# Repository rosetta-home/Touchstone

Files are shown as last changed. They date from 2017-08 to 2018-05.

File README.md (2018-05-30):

# Open Source Indoor Air Quality Sensor
An open hardware and software indoor air quality sensor provided by the [National Association of REALTORS](http://realtor.org) and [CRT Labs](https://crtlabs.org) in collaboration with the [Built Environment Research Group](http://built-envi.com/) at Illinois Institute of Technology.

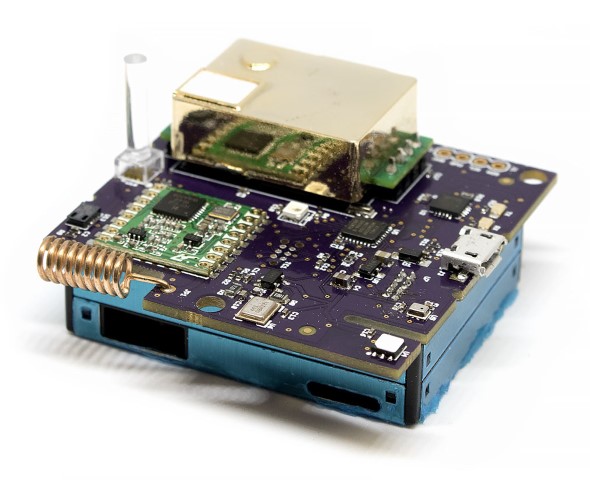
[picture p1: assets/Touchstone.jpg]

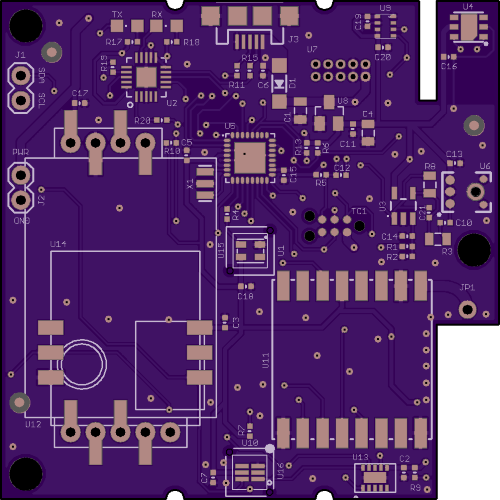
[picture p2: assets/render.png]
bruh


**Features**:
* Can measure upto 8 indoor environmental quality parameters (listed below)
* Atmel ATmega328P 16MHz 8-bit processor (based on Arduino platform)
* Genuine FTDI chip for serial communication with host computer
* Mini RGB LED for status and notification
* Programmable button for custom actions such as reset, configuration, etc.
* Long range wireless data transfer using FSK radio (no dependence on WiFi, cellular, etc.)
* Small footprint PCB board (less than 2x2 inches or 50x50mm)
* Low power requirements (35mA idle with all sensors running, 190mA peak during wireless data transfer)

**Measurement Points**:
* Temperature (Si7021)
* Relative Humidity (Si7021)
* VOC (Volatile Organic Compounds) (CCS811/IAQ-Core)
* CO2 (MH-z19)
* Particulate Matter, PM2.5 (PMS7003)
* Barometric Pressure (BMP280)
* Light Intensity (TSL2591)
* Sound Intensity (Electret Microphone)

**Connectivity**:
* FSK radio (RFM69HW 915MHz)
* MicroUSB (FTDI FX231XQ)

License:
Apache License Version 2.0

For the Raspberry Pi HAT, please visit the [PiAQ Website](http://piaq.io) and [repository](https://github.com/NationalAssociationOfRealtors/PiAQ)

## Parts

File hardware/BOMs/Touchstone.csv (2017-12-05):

Qty | Value | Device | Package | Parts | Description | AVAILABILITY | DESCRIPTION | MF | MP | MPN | OC_NEWARK | PACKAGE | PRICE | PROD_ID | SF_ID | SF_SKU | VALUE
2 |  | LEDCHIPLED_0805 | CHIPLED_0805 | RX, TX | LED |  |  |  |  | LG R971-KN-1 | unknown
2 |  | M02PTH | 1X02 | J1, J2 | Standard 2-pin 0.1 header. Use with"
12 | 0.1uF | MICROBUILDER_CAP_CERAMIC_0402MP | MICROBUILDER__0402MP | C3, C5, C6, C7, C8, C11, C12, C15, C16, C17, C19, C20 | Ceramic Capacitors |  |  |  |  | GRM155R71C104KA88J
2 | 0878980426 | 0878980426 | CONN_4POS_VERT_2.54_SMD | U$4, U$5 | CONN HEADER 4POS VERT 2.54MM SMD |  |  |  |  | 0878980426
2 | 100 | MICROBUILDER_RESISTOR_0402MP | MICROBUILDER__0402MP | R25, R32 | Resistors |  |  |  |  | RC0402FR-07100RL
2 | 100K | MICROBUILDER_RESISTOR_0402MP | MICROBUILDER__0402MP | R9, R12 | Resistors |  |  |  |  | RC0402FR-07100KL
11 | 10K | MICROBUILDER_RESISTOR_0402MP | MICROBUILDER__0402MP | R5, R6, R7, R10, R13, R16, R21, R26, R28, R29, R30 | Resistors |  |  |  |  | RC0402JR-0710KL
1 | 10uF | CAP0805 | 0805 | C4 | Capacitor |  |  |  |  | CC0805KKX5R6BB106
2 | 10uF | MICROBUILDER_CAP_CERAMIC_0402MP | MICROBUILDER__0402MP | C9, C22 | Ceramic Capacitors |  |  |  |  | GRJ155R60J106ME11D
2 | 120mA/40V/370mV | DIODE-SCHOTTKY-RB751S40 | SOD-523 | D3, D4 | Schottky diode |  |  |  |  | RB751S40T1G |  |  |  | DIO-11018 |  |  | 120mA/40V/370mV
1 | 16 MHz | RESONATORSMD | RESONATOR-SMD | X1 | Resonator |  |  |  |  | CSTCE16M0V53-R0
4 | 1K | MICROBUILDER_RESISTOR_0402MP | MICROBUILDER__0402MP | R19, R20, R22, R27 | Resistors |  |  |  |  | RC0402JR-071KL
1 | 1uF | CAP0805 | 0805 | C1 | Capacitor |  |  |  |  | CC0805ZRY5V8BB105
4 | 1uF | MICROBUILDER_CAP_CERAMIC_0402MP | MICROBUILDER__0402MP | C2, C18, C23, C24 | Ceramic Capacitors |  |  |  |  | CC0402KRX5R6BB105
1 | 2.2K | MICROBUILDER_RESISTOR_0402MP | MICROBUILDER__0402MP | R23 | Resistors |  |  |  |  | RC0402FR-072K2L
1 | 22K | MICROBUILDER_RESISTOR_0402MP | MICROBUILDER__0402MP | R31 | Resistors |  |  |  |  | RC0402JR-0722KL
2 | 27 | MICROBUILDER_RESISTOR_0402MP | MICROBUILDER__0402MP | R11, R15 | Resistors |  |  |  |  | RC0402JR-0727RL
3 | 470 | MICROBUILDER_RESISTOR_0402MP | MICROBUILDER__0402MP | R4, R17, R18 | Resistors |  |  |  |  | RC0402JR-07470RL
1 | 470K | MICROBUILDER_RESISTOR_0402MP | MICROBUILDER__0402MP | R24 | Resistors |  |  |  |  | RC0402FR-071ML
1 | 915MHz | RFM69HCW-915 | RFM69HCW-XXXS2 | U11 | Hope RF RFM69H ISM Transceiver Module |  |  |  |  | RFM69HCW |  |  |  | IC-11997 |  |  | 915MHz
1 | ATMEGA328P-MU | ATMEGA328P-MU | QFN50P500X500X100-33N | U5 | ATmega Series 20 MHz 32 KB Flash 2 KB SRAM 8-Bit Microcontroller - QFN-32 | Good | ATmega Series 20 MHz 32 KB Flash 2 KB SRAM 8-Bit Microcontroller - QFN-32 | Atmel | ATMEGA328P-MU | ATMEGA328P-MU |  | QFN-32 Atmel | 2.55 USD
1 | Antenna | PINHD-1X1CB | 1X01-CLEANBIG | JP1 | Pin header 1x1 for 0.1 spacing" |  |  |  |  | Helical antenna
1 | BMP280 | BMP280 | BMP280 | U9 | The BMP280 is an absolute barometric pressure sensor especially designed for mobile applications. The sensor module is housed in an extremely compact 8-pin metal-lid LGA package with a footprint of only 2.0 × 2.5 mm2 and 0.95 mm package height. Its small |  |  |  |  | BMP280
1 | CCS811-I2C | CCS811-I2C | LGA | U13 |  |  |  |  |  | CCS811
1 | CONN_HDR_1.27MM_SMD_4POS | CONN_HDR_1.27MM_SMD_4POS | CONN_HDR_1.27MM_SMD_4POS | U$6 | MPN: M50-3630442 |  |  |  |  | M50-3630442
4 | FIDUCIAL | FIDUCIAL | FIDUCIAL_1MM | U$1, U$2, U$3, U$7 | For use by pick and place machines to calibrate the vision/machine, 1mm
1 | FT231XQ-R | FT231XQ-R | FTDI_FT231XQ-R_PACKAGE | U2 | This is the 20-LD QFN package of the FTDI FT231XQ-R chip. |  |  |  |  | FT231XQ-R
1 | IAQ-CORE-C | IAQ-CORE-C | IAQ-CORE-C | U14 | AMS IAQ-Core |  |  |  |  | IAQ-CORE-C
1 | LMV324QT | LMV324QT | QFN-16_3X3 | U17 |  |  |  |  |  | LM324QT
1 | MCP1703CB | MCP1703CB | SOT23 | U8 | 250 mA, 16V, Low Quiescent Current LDO Regulator |  |  |  |  | MCP1703T-3302E/CB | 18T9177
1 | MH-Z19 | MH-Z19 | MH-Z19 | U12 | MH-z19 Footprint |  |  |  |  | MH-z19
1 | MIC2-PTH | MIC2-PTH | MICROPHONE-PTH-4.0MM | MK1 | Mini Electret Microphone |  |  |  |  | TOM-1545P-R |  |  |  | COMP-08856 | COM-08635
1 | MOMENTARY-SWITCH-SPST-SMD-6.0X3.5MM | MOMENTARY-SWITCH-SPST-SMD-6.0X3.5MM | TACTILE_SWITCH_SMD_6.0X3.5MM | S1 | Momentary Switch (Pushbutton) - SPST |  |  |  |  | RS-032G05A3-SM RT |  |  |  | SWCH-00815 |  | COM-08229
1 | NEOPIXEL_NANO_2427 | NEOPIXEL_NANO_2427 | SK6805-2427 | U1 |  |  |  |  |  | 3484
1 | PMS7003 | PMS7003 | PMS7003_RECEPTACLE_1.27MM_2X5 | U7 | 2x5 header 1.27mm pitch |  |  |  |  | 20021311-00012T4LF
1 | SI7021 | SI7021 | DFN-6-3X3-SI7021 | U4 | Silicon Labs Si7021 I2C Humidity and Temperature Sensor |  |  |  |  | SI7021-A20-GM1 |  |  |  | IC-13093
1 | SOD123 | MICROBUILDER_DIODE-SCHOTTKYSOD-123 | MICROBUILDER_SOD-123 | D1 |  |  |  |  |  | SD103AW-13-F
3 | STAND-OFF | STAND-OFF | STAND-OFF | H1, H2, H3 | #4 Stand Off
1 | TC2030-IDC-NL | TC2030-IDC-NL | TC2030-IDC-NL | TC1 | Tag-Connect In Circuit Programming & Debug Cable 6 Pin
1 | TSL2591 | LIGHT_TSL2591 | DFN6_TAOS | U10 | TSL2591 Light-To-Digital Sensor |  |  |  |  | TSL25911FN
1 | USB-MICROB | USB-MICROB | USB-MICROB | J3 | USB Connectors |  |  |  |  | ZX62-B-5PA(33) |  |  |  | CONN-09505
1 | VLP-450-F | VLP-450-F | VLP-450-F | U16 |  |  |  |  |  | VLP-550-F
1 | VLP-450-F | VLP-450-F | VLP-450-F | U15 |  |  |  |  |  | VLP-650-F

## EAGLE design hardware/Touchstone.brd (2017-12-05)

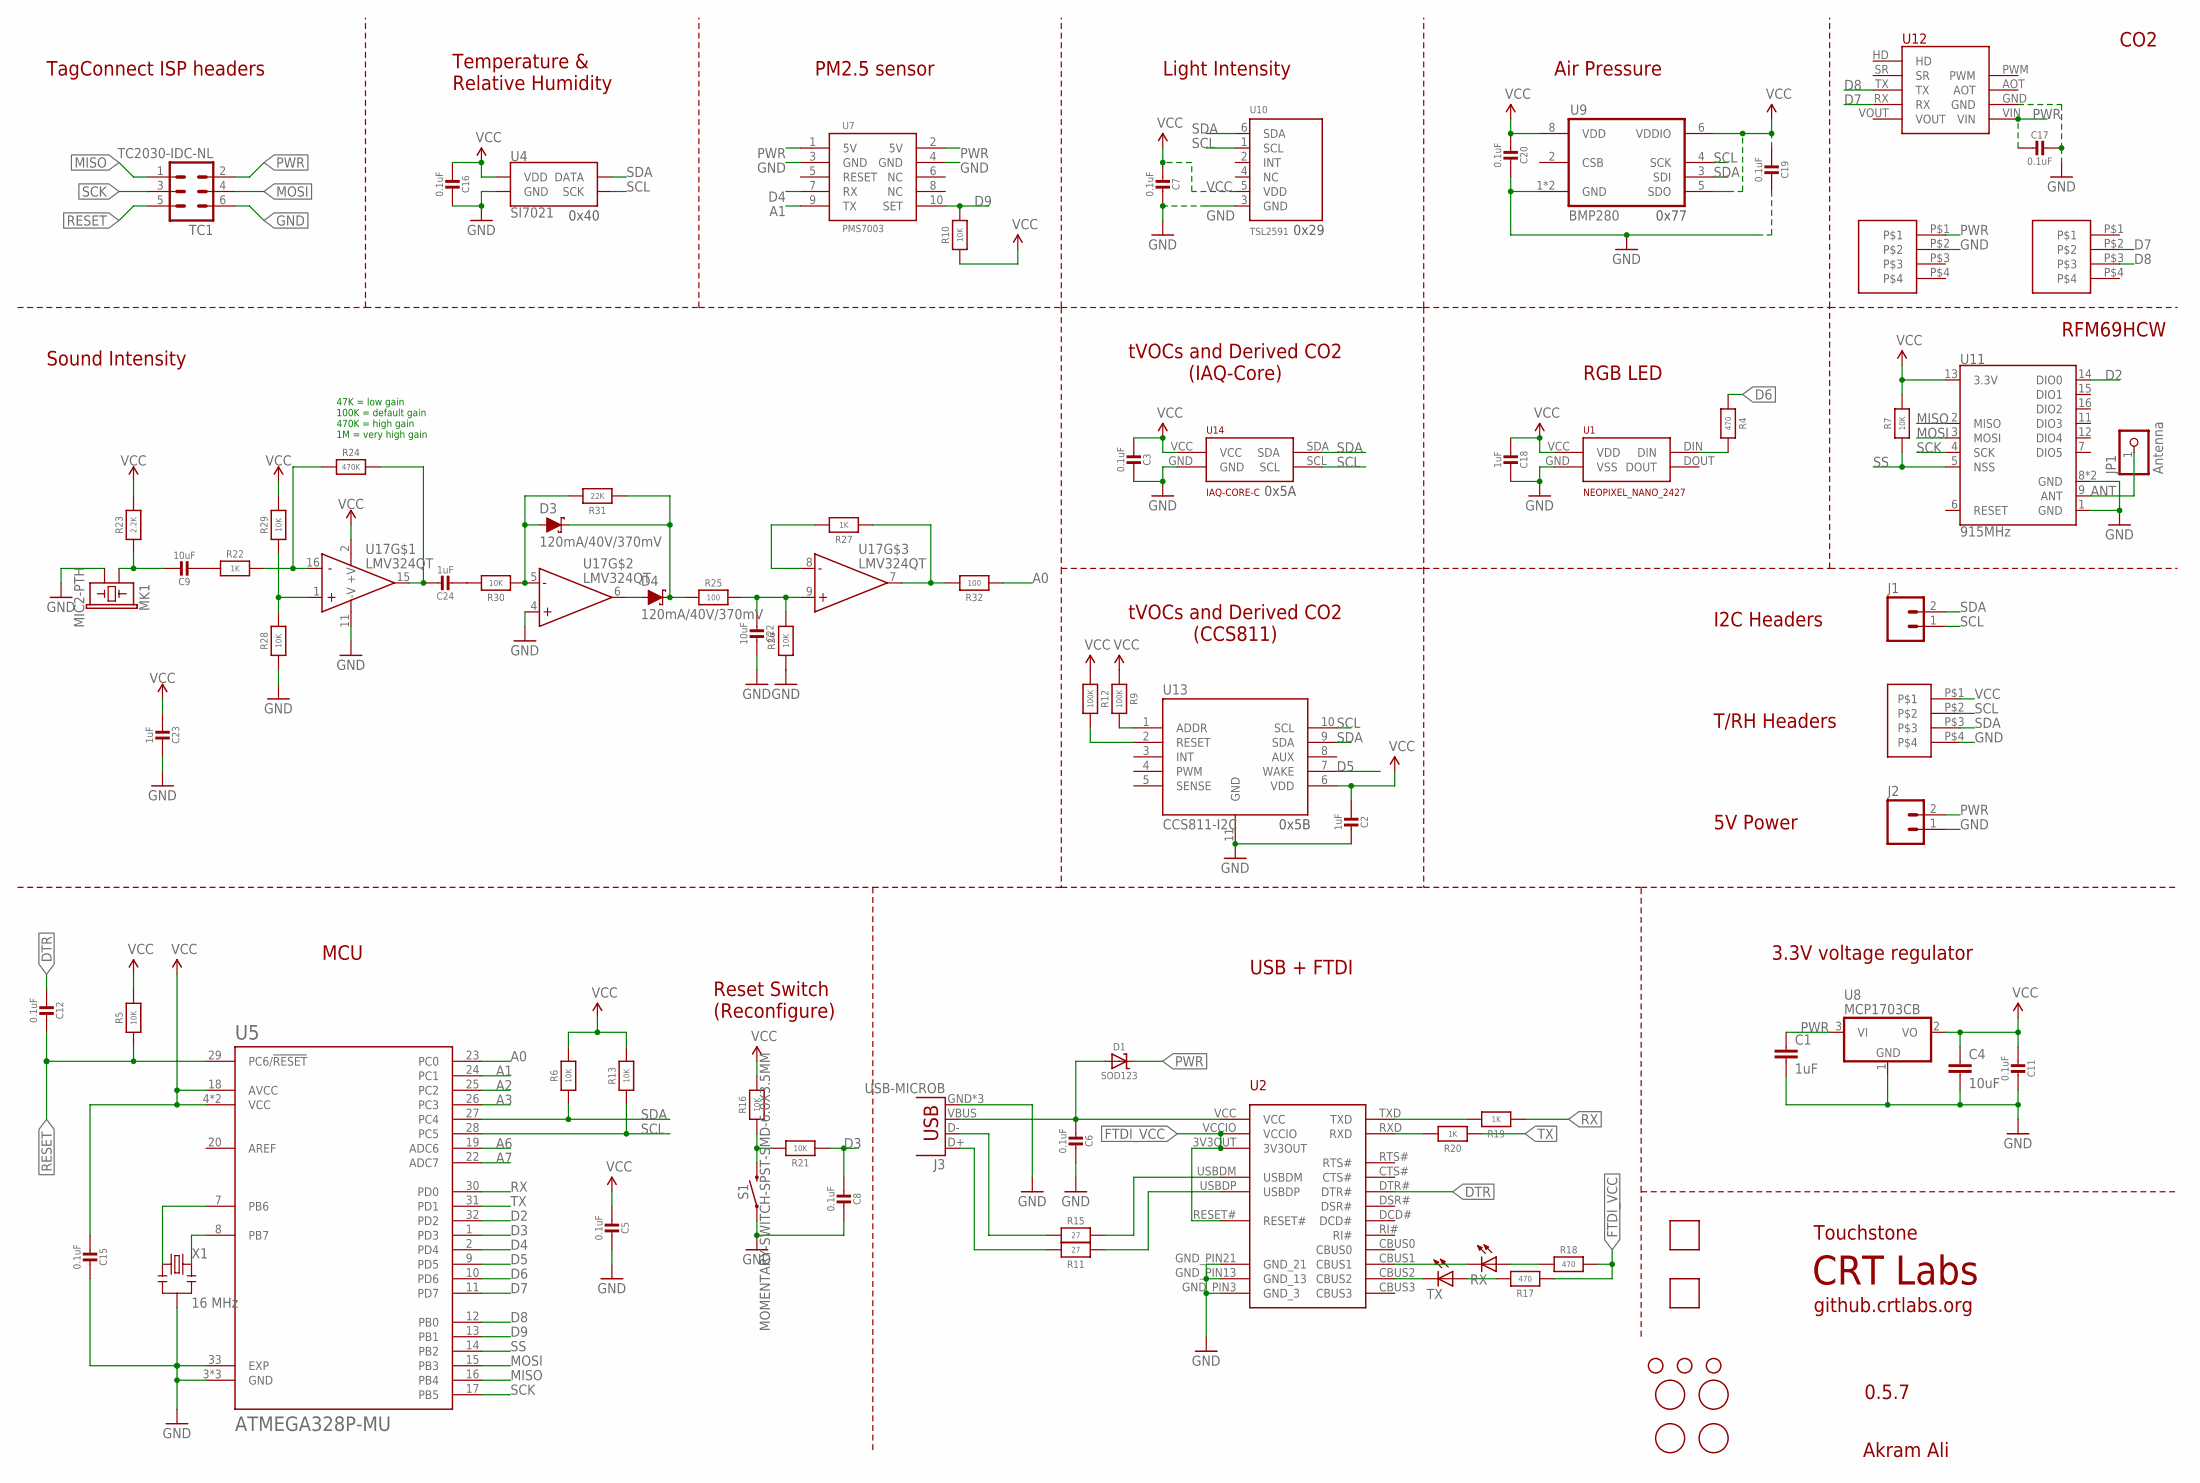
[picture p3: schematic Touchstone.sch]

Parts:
C1: 1uF; 0805; MPN CC0805ZRY5V8BB105
C2, C18, C23, C24: 1uF; MICROBUILDER__0402MP; MPN CC0402KRX5R6BB105
C3, C5, C6, C7, C8, C11, C12, C15, C16, C17, C19, C20: 0.1uF; MICROBUILDER__0402MP; MPN GRM155R71C104KA88J
C4: 10uF; 0805; MPN CC0805KKX5R6BB106
C9, C22: 10uF; MICROBUILDER__0402MP; MPN GRJ155R60J106ME11D
D1: SOD123; MICROBUILDER_SOD-123; MPN SD103AW-13-F
D3, D4: 120mA/40V/370mV; SOD-523; MPN RB751S40T1G
H1, H2, H3: STAND-OFF
J1, J2: M02PTH; 1X02
J3: USB-MICROB; MPN ZX62-B-5PA(33)
JP1: Antenna; 1X01-CLEANBIG; MPN Helical antenna
MK1: MIC2-PTH; MICROPHONE-PTH-4.0MM; MPN TOM-1545P-R
R4, R17, R18: 470; MICROBUILDER__0402MP; MPN RC0402JR-07470RL
R5, R6, R7, R10, R13, R16, R21, R26, R28, R29, R30: 10K; MICROBUILDER__0402MP; MPN RC0402JR-0710KL
R9, R12: 100K; MICROBUILDER__0402MP; MPN RC0402FR-07100KL
R11, R15: 27; MICROBUILDER__0402MP; MPN RC0402JR-0727RL
R19, R20, R22, R27: 1K; MICROBUILDER__0402MP; MPN RC0402JR-071KL
R23: 2.2K; MICROBUILDER__0402MP; MPN RC0402FR-072K2L
R24: 470K; MICROBUILDER__0402MP; MPN RC0402FR-071ML
R25, R32: 100; MICROBUILDER__0402MP; MPN RC0402FR-07100RL
R31: 22K; MICROBUILDER__0402MP; MPN RC0402JR-0722KL
RX: LEDCHIPLED_0805; CHIPLED_0805; MPN LG R971-KN-1
S1: MOMENTARY-SWITCH-SPST-SMD-6.0X3.5MM; TACTILE_SWITCH_SMD_6.0X3.5MM; MPN RS-032G05A3-SM RT
TC1: TC2030-IDC-NL
TX: LEDCHIPLED_0805; CHIPLED_0805; MPN LG R971-KN-1
U1: NEOPIXEL_NANO_2427; SK6805-2427; MPN 3484
U2: FT231XQ-R; FTDI_FT231XQ-R_PACKAGE; MPN FT231XQ-R
U4: SI7021; DFN-6-3X3-SI7021; MPN SI7021-A20-GM1
U5: ATMEGA328P-MU; QFN50P500X500X100-33N; MPN ATMEGA328P-MU
U7: PMS7003; PMS7003_RECEPTACLE_1.27MM_2X5; MPN 20021311-00012T4LF
U8: MCP1703CB; SOT23; MPN MCP1703T-3302E/CB
U9: BMP280; MPN BMP280
U10: TSL2591; DFN6_TAOS; MPN TSL25911FN
U11: 915MHz; RFM69HCW-XXXS2; MPN RFM69HCW
U12: MH-Z19; MPN MH-z19
U13: CCS811-I2C; LGA; MPN CCS811
U14: IAQ-CORE-C; MPN IAQ-CORE-C
U15: VLP-450-F; MPN VLP-650-F
U16: VLP-450-F; MPN VLP-550-F
U17: LMV324QT; QFN-16_3X3; MPN LM324QT
U$1, U$2, U$3, U$7: FIDUCIAL; FIDUCIAL_1MM
U$4, U$5: 0878980426; CONN_4POS_VERT_2.54_SMD; MPN 0878980426
U$6: CONN_HDR_1.27MM_SMD_4POS; MPN M50-3630442
X1: 16 MHz; RESONATOR-SMD; MPN CSTCE16M0V53-R0

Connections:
A0: R32.1, U5.23 (PC0)
A1: U5.24 (PC1), U7.9 (TX)
A2: U5.25 (PC2)
A3: U5.26 (PC3)
A6: U5.19 (ADC6)
A7: U5.22 (ADC7)
AMP: C24.1, R24.2, U17.15 (OUT)
ANT: JP1.1, U11.9 (ANT)
D2: U5.32 (PD2), U11.14 (DIO0)
D3: C8.2, R21.1, U5.1 (PD3)
D4: U5.2 (PD4), U7.7 (RX)
D5: U5.9 (PD5), U13.7 (WAKE)
D6: R4.1, U5.10 (PD6)
D7: U5.11 (PD7), U12.RX, U$5.P$2
D8: U5.12 (PB0), U12.TX, U$5.P$3
D9: R10.2, U5.13 (PB1), U7.10 (SET)
DTR: C12.2, U2.DTR#
FTDI_VCC: R17.1, R18.2, U2.3V3OUT, U2.RESET#, U2.VCCIO
GND: C1.2, C2.1, C3.1, C4.2, C5.1, C6.1, C7.1, C8.1, C11.1, C15.1, C16.1, C17.1, C18.1, C19.1, C20.1, C22.1, C23.1, J2.1, J3.GND, J3.MT1 (GND), J3.MT2 (GND), MK1.GND (2), R26.1, R28.1, S1.1, TC1.6, U1.GND (VSS), U2.GND_PIN3 (GND_3), U2.GND_PIN13 (GND_13), U2.GND_PIN21 (GND_21), U4.GND, U5.3 (GND), U5.5 (GND), U5.21 (GND), U5.33 (EXP), U7.3 (GND), U7.4 (GND), U8.1 (GND), U9.1 (GND), U9.7 (GND), U10.3 (GND), U11.1 (GND), U11.8 (GND), U11.10 (GND), U12.GND, U13.11 (GND), U14.GND, U17.4 (+IN), U17.11 (-V), U$4.P$2, U$6.P$4, X1.2
MISO: TC1.1, U5.16 (PB4), U11.2 (MISO)
MOSI: TC1.4, U5.15 (PB3), U11.3 (MOSI)
unnamed: R4.2, U1.DIN
unnamed: R20.2, U2.RXD
unnamed: R19.2, U2.TXD
unnamed: U5.8 (PB7), X1.3
unnamed: U5.7 (PB6), X1.1
unnamed: R12.2, U13.2 (RESET)
unnamed: R16.1, R21.2, S1.2
unnamed: C9.2, R22.1
unnamed: C9.1, MK1.OUT (1), R23.1
unnamed: R22.2, R24.1, U17.16 (-IN)
unnamed: R9.2, U13.1 (ADDR)
unnamed: D3.C, D4.C, R25.1, R31.1
unnamed: R27.2, U17.8 (-IN)
unnamed: RX.C, U2.CBUS1
unnamed: TX.C, U2.CBUS2
unnamed: C24.2, R30.2
unnamed: C22.2, R25.2, R26.2, U17.9 (+IN)
unnamed: D4.A, U17.6 (OUT)
unnamed: D3.A, R30.1, R31.2, U17.5 (-IN)
unnamed: R15.2, U2.USBDM
unnamed: R11.1, U2.USBDP
unnamed: R18.1, RX.A
unnamed: R17.2, TX.A
unnamed: J3.D-, R15.1
unnamed: J3.D+, R11.2
PWR: C1.1, C17.2, D1.C, J2.2, TC1.2, U7.1 (5V), U7.2 (5V), U8.3 (VI), U12.VIN, U$4.P$1
RESET: C12.1, R5.1, TC1.5, U5.29 (PC6/!RESET)
RX: R19.1, U5.30 (PD0)
SCK: TC1.3, U5.17 (PB5), U11.4 (SCK)
SCL: J1.1, R13.1, U4.SCK, U5.28 (PC5), U9.4 (SCK), U10.1 (SCL), U13.10 (SCL), U14.SCL, U$6.P$2
SDA: J1.2, R6.1, U4.DATA, U5.27 (PC4), U9.3 (SDI), U10.6 (SDA), U13.9 (SDA), U14.SDA, U$6.P$3
SS: R7.1, U5.14 (PB2), U11.5 (NSS)
TX: R20.1, U5.31 (PD1)
VBUS: C6.2, D1.A, J3.VBUS, U2.VCC
VCC: C2.2, C3.2, C4.1, C5.2, C7.2, C11.2, C15.2, C16.2, C18.2, C19.2, C20.2, C23.2, R5.2, R6.2, R7.2, R9.1, R10.1, R12.1, R13.2, R16.2, R23.2, R29.2, U1.VCC (VDD), U4.VDD, U5.4 (VCC), U5.6 (VCC), U5.18 (AVCC), U8.2 (VO), U9.5 (SDO), U9.6 (VDDIO), U9.8 (VDD), U10.5 (VDD), U11.13 (3.3V), U13.6 (VDD), U14.VCC, U17.2 (+V), U$6.P$1
VCC/2: R28.2, R29.1, U17.1 (+IN)
_OUT: R27.1, R32.2, U17.7 (OUT)

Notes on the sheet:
Light Intensity
tVOCs and Derived CO2 (IAQ-Core)
Air Pressure
Sound Intensity
Temperature & Relative Humidity
TagConnect ISP headers
3.3V voltage regulator
CRT Labs
Touchstone
Akram Ali
USB + FTDI
0x5A
0x77
0.5.7
github.crtlabs.org
0x29
RGB LED
I2C Headers
PM2.5 sensor
RFM69HCW
MCU
CO2
tVOCs and Derived CO2 (CCS811)
5V Power
0x5B
0x40
T/RH Headers
Reset Switch (Reconfigure)
47K = low gain 100K = default gain 470K = high gain 1M = very high gain

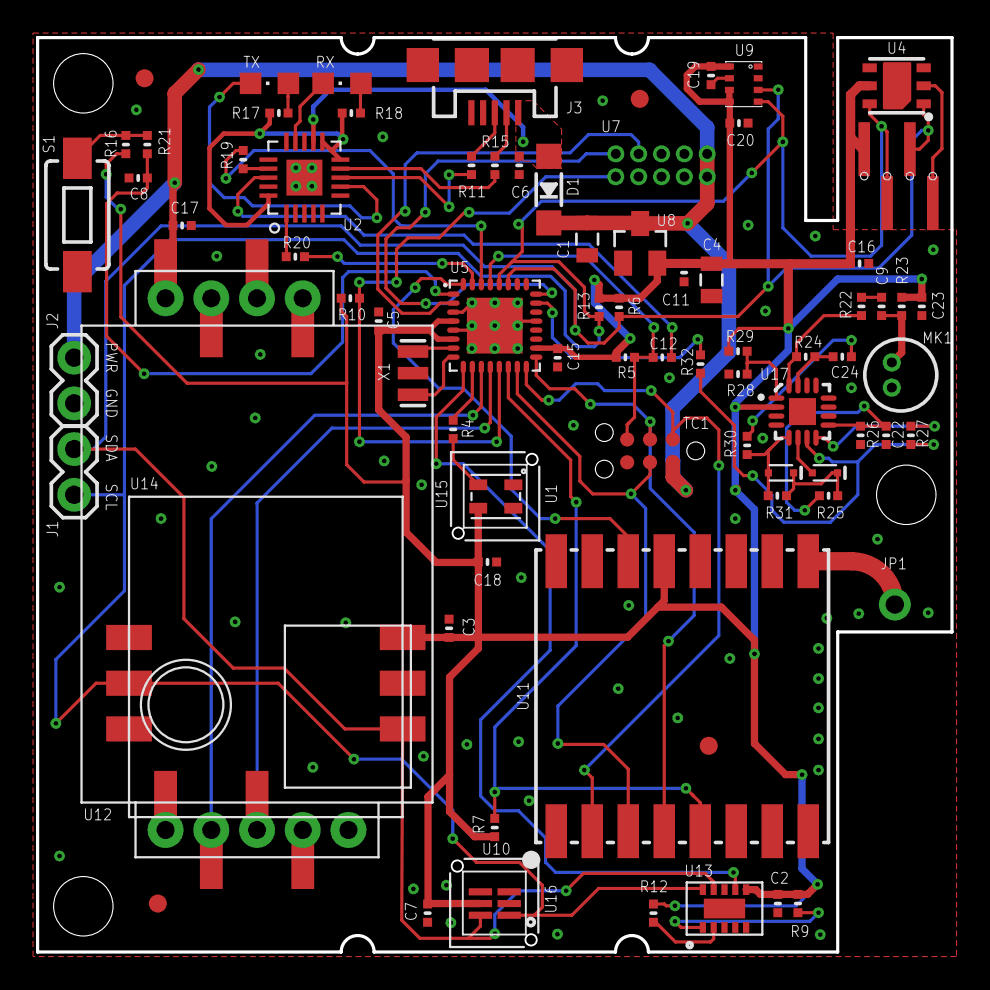
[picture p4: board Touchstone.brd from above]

Board: 2 copper layers, 50.8 x 50.8 mm, 85 parts (1 on the bottom side), 54 nets.

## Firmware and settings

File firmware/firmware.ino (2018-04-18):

// v0.5.7 - 10/19/2017
// Developed by Akram Ali

// www.crtlabs.org

#include <RFM69.h>  //  https://github.com/LowPowerLab/RFM69
#include <SPI.h>
#include <Arduino.h>
#include <Wire.h>
#include <CCS811.h> // https://github.com/AKstudios/CCS811-library
//#include <Adafruit_SHT31.h> //https://github.com/adafruit/Adafruit_SHT31
#include <Adafruit_Si7021.h> // https://github.com/adafruit/Adafruit_Si7021
#include <Adafruit_BMP280.h> // https://github.com/adafruit/Adafruit_BMP280_Library
#include <Adafruit_Sensor.h>  // https://github.com/adafruit/Adafruit_Sensor
#include <Adafruit_TSL2591.h> // https://github.com/adafruit/Adafruit_TSL2591_Library
#include <Adafruit_NeoPixel.h> // https://github.com/adafruit/Adafruit_NeoPixel
#include <SoftwareSerial.h>
#include <avr/sleep.h>
#include <avr/wdt.h>
#include "config.h"

// define node parameters
//char node[] = "25";
//#define NODEID        25 // same sa above - must be unique for each node on same network (range up to 254, 255 is used for broadcast)
#define GATEWAYID     1
#define NETWORKID     101
#define FREQUENCY     RF69_915MHZ //Match this with the version of your Moteino! (others: RF69_433MHZ, RF69_868MHZ)
#define IS_RFM69HW    //uncomment only for RFM69HW! Leave out if you have RFM69W!
//#define LED           9 // led pin
#define PIN           6 // NeoPixel driver pin

// define objects
RFM69 radio;
Adafruit_BMP280 bme; // I2C
//Adafruit_SHT31 sht31 = Adafruit_SHT31();
Adafruit_Si7021 sensor = Adafruit_Si7021();
Adafruit_TSL2591 tsl = Adafruit_TSL2591(2591); // pass in a number for the sensor identifier (for your use later)
Adafruit_NeoPixel strip = Adafruit_NeoPixel(1, PIN, NEO_GRB + NEO_KHZ800);  // number of pixels, digital pin, pixel flags

/*
// define IAQ core global variables
#define iaqaddress 0x5A
uint16_t co2;
uint8_t statu;
int32_t resistance;
uint16_t tvoc;
*/

// define CCS811 global variables
#define ADDR      0x5B
#define WAKE_PIN  5
CCS811 ccs811_sensor;
uint16_t tvoc;

// define MH-z19 global variables
SoftwareSerial mySerial(8, 7); // RX, TX
byte cmd[9] = {0xFF,0x01,0x86,0x00,0x00,0x00,0x00,0x00,0x79};
unsigned char response[18]; // expect a 9 bytes response, give twice the size just in case things go crazy, it reduces likelyhood of crash/buffer overrun

// define PMS7003 global variables
SoftwareSerial mySerial2(A1, 4); // RX, TX
char buf[31];
long CF1PM01Value,CF1PM25Value,CF1PM10Value,atmPM01Value,atmPM25Value,atmPM10Value,Partcount0_3,Partcount0_5,Partcount1_0,Partcount2_5,Partcount5_0,Partcount10;

// define other global variables
long lux;
float bar;
float sound;
int ppm, _ppm;
float co2;

char dataPacket[150];

ISR(WDT_vect)  // Interrupt Service Routine for WatchDog Timer
{
  wdt_disable();  // disable watchdog
}


void ISR_button()  // Interrupt Service Routine for button press
{
  for (int i = 0; i <= 255; i++)
  {
      colorWipe(strip.Color(0,0,i), 1);  // blue
  }
  for (int i = 255; i > 0; i--)
  {
      colorWipe(strip.Color(0,0,i), 2);  // blue
  }
  colorWipe(strip.Color(0, 0, 0), 1); // turn pixel off
  strip.show();
}


void setup()
{
  pinMode(10, OUTPUT); // Radio SS pin set as output

  Serial.begin(115200);
  Serial.println("Setup");

  //pinMode(3, INPUT);
  attachInterrupt(1, ISR_button, FALLING);  // enable hardware interrupt on pin 3 when pin goes from HIGH to LOW

  ccs811_sensor.begin(uint8_t(ADDR), uint8_t(WAKE_PIN));  // initialize CCS811 sensor

  mySerial.begin(9600);   // initialize MHz-19 in UART mode
  mySerial2.begin(9600);   // initialize PMS7003 in UART mode

  while(mySerial2.available() > 0)  // clear out buffer
    char x = mySerial2.read();
  delay(1);

  radio.initialize(FREQUENCY,NODEID,NETWORKID);
#ifdef IS_RFM69HW
  radio.setHighPower(); //uncomment only for RFM69HW!
#endif
  radio.encrypt(ENCRYPTKEY);

  //pinMode(9, OUTPUT);  // pin 9 controls LED

  strip.begin(); // initialize neo pixels
  strip.show(); // Initialize all pixels to 'off'

  // get first CO2 reading
  while(mySerial.available() > 0)  // clear out buffer
    char x = mySerial.read();
  mySerial.write(cmd,9);
  delay(1);
  if(mySerial.available() > 0 && (unsigned char)mySerial.peek() != 0xFF)
    mySerial.read();
  mySerial.readBytes(response, 9);
  unsigned int responseHigh = (unsigned int) response[2];
  unsigned int responseLow = (unsigned int) response[3];
  ppm = (256 * responseHigh) + responseLow;
  _ppm = ppm;

  Serial.println("Ready");
  delay(10);
}


void sleep()
{
  Serial.flush(); // empty the send buffer, before continue with; going to sleep

  radio.sleep();

  cli();          // stop interrupts
  MCUSR = 0;
  WDTCSR  = (1<<WDCE | 1<<WDE);     // watchdog change enable
  WDTCSR  = 1<<WDIE | (1<<WDP3) | (0<<WDP2) | (0<<WDP1) | (1<<WDP0); // set  prescaler to 8 second
  sei();  // enable global interrupts

  byte _ADCSRA = ADCSRA;  // save ADC state
  ADCSRA &= ~(1 << ADEN);

  asm("wdr");
  set_sleep_mode(SLEEP_MODE_PWR_DOWN);
  cli();

  sleep_enable();
  sleep_bod_disable();
  sei();
  sleep_cpu();

  sleep_disable();
  sei();

  ADCSRA = _ADCSRA; // restore ADC state (enable ADC)
  delay(1);
}


void loop()
{
  sleep();
  readSensors();

  Serial.println(dataPacket);
  delay(50);

  // send datapacket
  radio.sendWithRetry(GATEWAYID, dataPacket, strlen(dataPacket), 5, 100);  // send data, retry 5 times with delay of 100ms between each retry
  dataPacket[0] = (char)0; // clearing first byte of char array clears the array

  //colorWipe(strip.Color(0, 255, 0), 10); // Green
  //strip.show();

  for (int i = 0; i <= 255; i++)
  {
      colorWipe(strip.Color(0,i,0), 1);
  }
  for (int i = 255; i > 0; i--)
  {
      colorWipe(strip.Color(0,i,0), 2);
  }
  colorWipe(strip.Color(0, 0, 0), 1); // turn pixel off
  strip.show();
}


void readSensors()
{
  /*
  // T/RH - SHT31
  sht31.begin(0x44);
  float temp = sht31.readTemperature();
  float rh = sht31.readHumidity();
  */

  // T/RH - Si7021
  sensor.begin();
  float temp = sensor.readTemperature();
  temp = temp - 2;
  float rh = sensor.readHumidity();
  rh = rh + 5;


  // Light Intensity - TSL2591
  tsl.begin();
  tsl.setGain(TSL2591_GAIN_MED);      // 25x gain
  tsl.setTiming(TSL2591_INTEGRATIONTIME_100MS);  // shortest integration time (bright light)
  sensors_event_t event;
  tsl.getEvent(&event);
  if ((event.light == 0) | (event.light > 4294966000.0) | (event.light <-4294966000.0))
  {
    lux = 0;  // invalid value; replace with 'NAN' if needed
  }
  else
  {
    lux = event.light;
  }

  /*
  // IAQ core
  Wire.requestFrom(iaqaddress, 9);
  co2 = (Wire.read()<< 8 | Wire.read());
  statu = Wire.read();
  resistance = (Wire.read()& 0x00)| (Wire.read()<<16)| (Wire.read()<<8| Wire.read());
  tvoc = (Wire.read()<<8 | Wire.read());
  */

  // MH-z19 UART
  mySerial.listen();
  delay(1);
  while(mySerial.available() > 0)  // clear out buffer
    char x = mySerial.read();
  mySerial.write(cmd,9);
  delay(1);
  if(mySerial.available() > 0 && (unsigned char)mySerial.peek() != 0xFF)
    mySerial.read();
  mySerial.readBytes(response, 9);
  unsigned int responseHigh = (unsigned int) response[2];
  unsigned int responseLow = (unsigned int) response[3];
  ppm = (256 * responseHigh) + responseLow;
  co2 = (0.7*ppm) + (0.3*_ppm);  // real-time exponential smoothing of data with a damping factor of 0.3
  _ppm = (int)co2;  // save old reading;

  /*
  // ADMP401 mic for sound level
  float sumADC=0.0;
  for(int i=0;i<5;i++)
  {
     sumADC = sumADC + analogRead(A0); // take avg of 5 readings
  }
  float averageADC = sumADC/5.0;
  float volts = (averageADC/1023.0 * 3.3);
  sound = (20 * log10(volts/0.007943)) - 42 + 94 - 60;  // VRMS = 0.007943; -42dB is sensitivity of ADMP401 mic; 1 Pa = 94 dB SPL RMS; 60dB is gain of amplifier
  // the above is uncalibrated sound level - needs to be calibrated with reference to an accurate sound level meter in varying SPLs, frequencies and environments.
  //sound = averageADC;
  */

  // Sound levels using electret mic
  float sumADC=0.0;
  for(int i=0;i<2;i++)
  {
     sumADC = sumADC + analogRead(A0); // take avg of 2 readings
  }
  float averageADC = sumADC/2.0;
  sound = 52.864 * (exp(0.0011 * averageADC));  // roughly calibrated sound levels (in dB) in a typical office environment using a reference sound level meter (SLM01)


  // BMP280 air pressure sensor
  bme.begin();
  float bar = bme.readPressure();
  bar = bar / 3386.39;  // convert pressure in Pa to inches of Mercury


  // CCS811 VOC readings
  ccs811_sensor.compensate(temp, rh);  // environmental compensation for current temperature and humidity
  ccs811_sensor.getData();
  tvoc = ccs811_sensor.readTVOC();


  // PMS7003
  char response[10];
  long pm;
  //while(mySerial2.available() > 0)  // clear out buffer
  //  char x = mySerial2.read();
  delay(1);
  mySerial2.listen();
  delay(1);
  //if(mySerial2.available()>0)
  //  mySerial2.read();
  //mySerial2.readBytes(buf, 31);
  if (mySerial2.find(0x42))
  {
      mySerial2.readBytes(buf, 31);
      get_data(buf);
  }
  delay(1);
  //get_data(buf);
  //Serial.println(buf);
  //Serial.println(atmPM01Value);
  pm = atmPM01Value;


  // define character arrays for all variables
  char _i[3];
  char _t[7];
  char _h[7];
  char _c[7];
  char _o[7];
  char _g[7];
  char _l[7];
  char _n[7];
  char _s[7];
  char _v[7];
  char _p[7];

  // convert all flaoting point and integer variables into character arrays
  dtostrf(NODEID, 1, 0, _i);
  dtostrf(temp, 3, 2, _t);  // this function converts float into char array. 3 is minimum width, 2 is decimal precision
  dtostrf(rh, 3, 2, _h);
  dtostrf(co2, 3, 0, _c);
  dtostrf(bar, 3, 2, _g);
  dtostrf(lux, 1, 0, _l);
  dtostrf(sound, 1, 1, _s);
  dtostrf(tvoc, 1, 0, _v);
  dtostrf(pm, 1, 0, _p);
  delay(50);

  dataPacket[0] = 0;  // first value of dataPacket should be a 0

  // create datapacket by combining all character arrays into a large character array
  strcat(dataPacket, "i:");
  strcat(dataPacket, _i);
  strcat(dataPacket, ",t:");
  strcat(dataPacket, _t);
  strcat(dataPacket, ",h:");
  strcat(dataPacket, _h);
  strcat(dataPacket, ",c:");
  strcat(dataPacket, _c);
  strcat(dataPacket, ",g:");
  strcat(dataPacket, _g);
  strcat(dataPacket, ",l:");
  strcat(dataPacket, _l);
  strcat(dataPacket, ",s:");
  strcat(dataPacket, _s);
  strcat(dataPacket, ",p:");
  strcat(dataPacket, _p);
  strcat(dataPacket, ",v:");
  strcat(dataPacket, _v);
  delay(50);
}


void get_data(unsigned char b[])
{
  int receiveSum = 0;
  for (int i = 0; i < (31 - 2); i++)
  {
    receiveSum = receiveSum + b[i];
  }
  receiveSum = receiveSum + 0x42;
  receiveSum == ((b[31 - 2] << 8) + b[31 - 1]);

  if(b[0] == 0x4D && receiveSum)
  {
    CF1PM01Value = (b[9] << 8) + b[10]; //PM1.0 CF1 value of the air detector module
    CF1PM25Value = (b[5] << 8) + b[6]; //PM2.5 CF1 value of the air detector module
    CF1PM10Value = (b[7] << 8) + b[8]; //PM10 CF1 value of the air detector module

    atmPM01Value = (b[3] << 8) + b[4]; //PM1.0 atmospheric value of the air detector module
    atmPM25Value = (b[11] << 8) + b[12]; //PM2.5 atmospheric value of the air detector module
    atmPM10Value = (b[13] << 8) + b[14]; //PM10 atmospheric value of the air detector module

    Partcount0_3 = (b[15] << 8) + b[16]; //count particules > 0.3 µm
    Partcount0_5 = (b[17] << 8) + b[18]; //count particules > 0.5 µm
    Partcount1_0 = (b[19] << 8) + b[20]; //count particules > 1.0 µm
    Partcount2_5 = (b[21] << 8) + b[22]; //count particules > 2.5 µm
    Partcount5_0 = (b[23] << 8) + b[24]; //count particules > 5.0 µm
    Partcount10 = (b[25] << 8) + b[26]; //count particules > 10.0 µm
  }
}

/*
void fadeLED()
{
  int brightness = 0;
  int fadeAmount = 5;
  for(int i=0; i<510; i=i+5)  // 255 is max analog value, 255 * 2 = 510
  {
    analogWrite(9, brightness);  // pin 9 is LED

    // change the brightness for next time through the loop:
    brightness = brightness + fadeAmount;  // increment brightness level by 5 each time (0 is lowest, 255 is highest)

    // reverse the direction of the fading at the ends of the fade:
    if (brightness <= 0 || brightness >= 255)
    {
      fadeAmount = -fadeAmount;
    }
    // wait for 20-30 milliseconds to see the dimming effect
    delay(10);
  }
  digitalWrite(9, LOW); // switch LED off at the end of fade
}
*/



// Fill the dots one after the other with a color
void colorWipe(uint32_t c, uint8_t wait) {
  for(uint16_t i=0; i<strip.numPixels(); i++) {
    strip.setPixelColor(i, c);
    strip.show();
    delay(wait);
  }
}

// bruh

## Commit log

2017-08-07 Adds arduino libraries as submodules
2017-08-14 Added pullups on CCS811's signal lines
    RESET AND WAKE lines pulled up by default
    [Touchstone.brd, Touchstone.sch]
2017-08-14 Added SMD pads for T/RH breakout
    [Touchstone.brd, Touchstone.sch]
2017-08-14 Version number change; minor adjustments
    - Changed version number to 0.5.7 (new versioning format)
    - silkscreen adjustments
    - some schematic rearrangements
    [Touchstone.brd, Touchstone.sch]
2017-08-15 Added reset button
    - added momentary tactile button for resetting device (reconfiguring,
    not power cycle)
    - added other circuitry for button
    - moved I2C headers to make space for reset button
    - several traces redone to accomodate button
    - minor silkscreen adjustment
    - DRC/ERC checked
    [Touchstone.brd, Touchstone.sch]
2017-08-15 Several routing adjustments
    - PMS7003 TX rewired from D3 to A1 (D3 is INT pin)
    - Button reqired from A1 to D3 (same reason above)
    - adjusted several traces to account for the above rewiring
    - Added several GND vias under MCU and FTDI (heatsink - may help a tiny
    bit)
    - minor silkscreen adjustments to account for above
    [Touchstone.brd, Touchstone.sch]
2017-08-15 Added another fiducial marker
    - rearranged fiducials a bit
    - minor schematic update
    [Touchstone.brd, Touchstone.sch]
2017-08-15 CRT silkscreen minor update
    [Touchstone.brd]
2017-08-28 Updated BOM
    MPN added for all parts
    [Touchstone.brd, Touchstone.sch]
2017-08-28 Added BOM csv
    [Touchstone.csv]
2017-09-18 v0.5.7 - updated sound level circuit
    - Replaced MEMS mic with mini electret mic
    - Added analog circuitry for the mic
    - Some routing and silkscreen adjustments
    [Touchstone.brd, Touchstone.sch]
2017-09-18 Fix conflicts
    - file got corrupted - fixed by restoring v7 file and saving as v8
    [Touchstone.brd, Touchstone.csv, Touchstone.sch]
2017-09-18 Updated BOM
    Added MPN for all components
    [Touchstone.brd, Touchstone.sch, Touchstone_BOM.csv]
2017-10-30 Bug fixes
    - Removed pullup from WAKE pin of CSS811 (stopped chip from working)
    - Adjusted value of resistor on sound circuit to 1M (to increase gain to
    a LOT)
    - Minor trace and silkscreen adjustments
    - BOM update
    [Touchstone.brd, Touchstone.sch]
2017-10-30 BOM update
    - 1M resistor added
    - 100K resistor removed
    [Touchstone_BOM.csv]
2017-10-30 PCB adjustments
    - Aligned a reistor properly
    - Removed some GND vias from underneath the MCU (paste was leaking
    through)
    [Touchstone.brd]
2017-12-05 Added gerbers and BOM
    - Also updated firmware for button interrupt, sound level stuff
    [Touchstone.brd, Touchstone.csv, Touchstone.sch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]

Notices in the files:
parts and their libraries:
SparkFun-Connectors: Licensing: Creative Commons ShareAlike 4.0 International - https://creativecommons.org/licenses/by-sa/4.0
